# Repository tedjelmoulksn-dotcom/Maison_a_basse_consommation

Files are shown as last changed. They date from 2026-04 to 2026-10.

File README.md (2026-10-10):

# Embedded Energy-Efficient House

An Arduino-based house demonstrator integrating temperature measurement, thermal actuation and motorized mechanisms. The project connects embedded control software with an energy-efficiency study and a physical model.

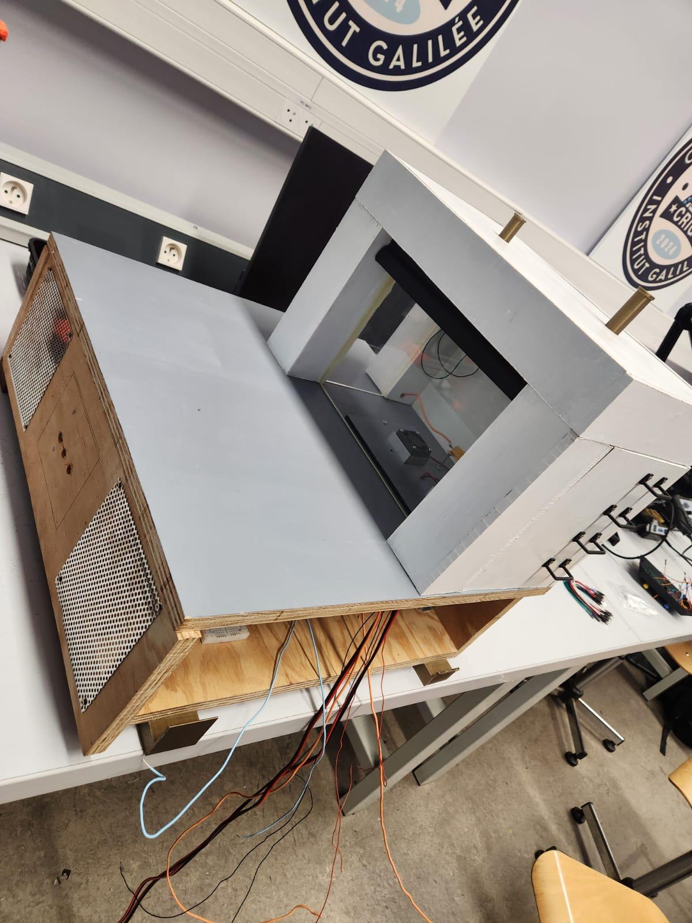
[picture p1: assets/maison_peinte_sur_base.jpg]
Maison a basse consommation project overview


*Assembled house model with its integrated control hardware.*

## Embedded architecture

The firmware reads a **TCN75A temperature sensor over I²C** and presents information on a **20 × 4 I²C LCD**. Buttons select operating modes. GPIO and PWM outputs drive heating, a Peltier element, ventilation and a simulated sun source; a stepper motor and servo control the mechanical demonstration.

| Interface | Implementation |
| --- | --- |
| Temperature acquisition | TCN75A at address `0x48`, local C++ driver |
| Display | LCD at address `0x27` |
| User input | Buttons with internal pull-ups |
| Actuation | Heater, Peltier, fan, light, stepper and servo |
| Diagnostics | Serial output at 9600 baud |

## Repository guide

- [arduino](arduino/): application sketch, sensor driver and shutter support.
- [cad](cad/): mechanical design files.
- [documentation](documentation/): report and poster.
- [assets](assets/): prototype photographs.
- [tests](tests/): host-side checks and Arduino stubs.

## Getting started

Open the sketch in Arduino IDE and install its LCD, stepper and servo dependencies. Confirm the pin assignments in the sketch against the wiring before uploading.

The supplied software includes demonstration modes and component-level tests. Full thermal regulation and assembled-system behaviour require validation on the physical prototype.

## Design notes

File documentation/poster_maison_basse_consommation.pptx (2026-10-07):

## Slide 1

Maquette d’une maison énergétique intelligente : régulation thermique autonome

Greg ALBERTS, Sarah DAHMOUN, Hugo LEBAUD, Tedj El Moulk SINACER
Encadrant : Gabriel DUTIER, LPL, gabriel.dutier@univ-paris13.fr

Cycle ingénieur 2ème année – Instrumentation et Systèmes Embarqués – Sup Galilée – USPN

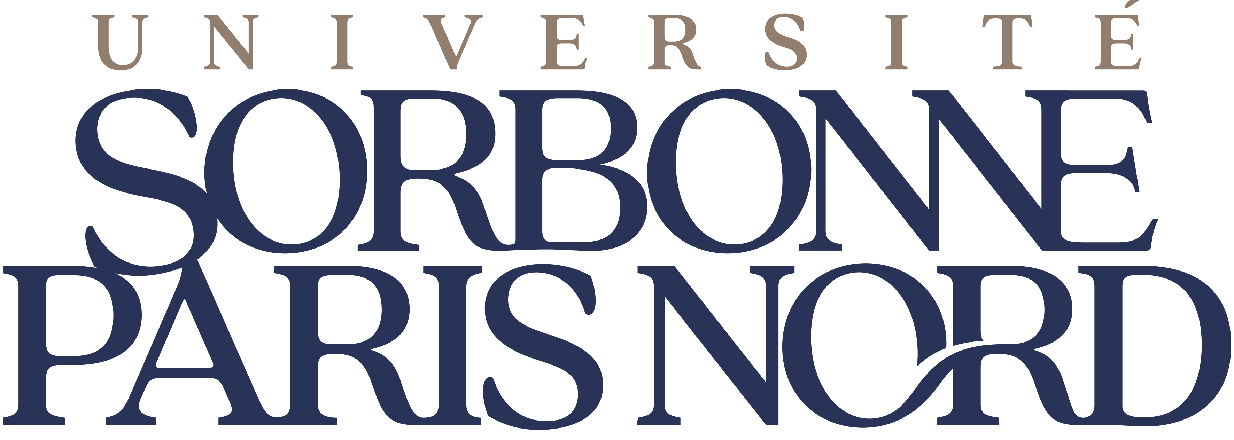
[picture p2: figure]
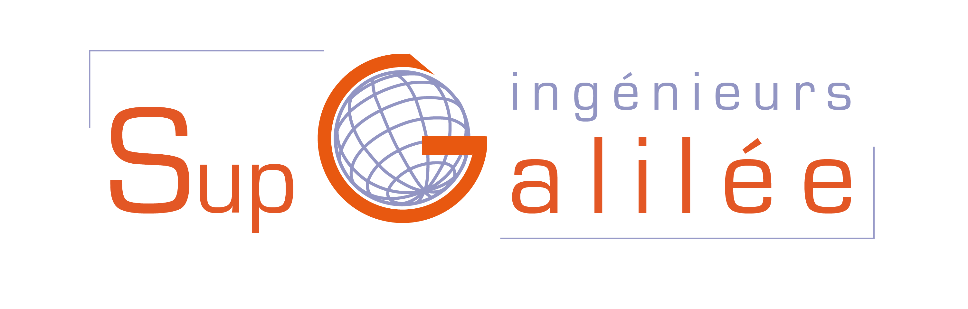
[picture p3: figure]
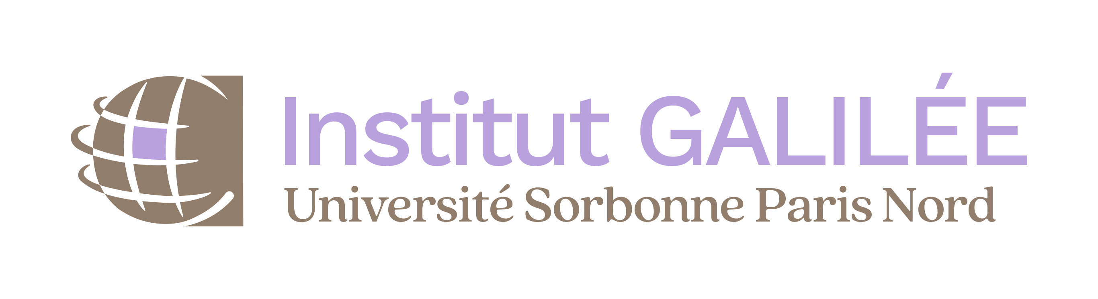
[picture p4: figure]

1- Contexte et objectif
Contexte :
- En France et en Europe le secteur du bâtiment représente
environ 40% de la consommation énergétique totale.
- L’optimisation des systèmes de régulation thermique est
un levier concret d’action
Pourquoi une maquette ?
- Permet de tester des solutions en conditions simulées
- Reproduire le comportement thermique d’une maison
à petite échelle

Objectif :
Créer une maison miniature capable de réguler sa température selon la saison et en autonomie.

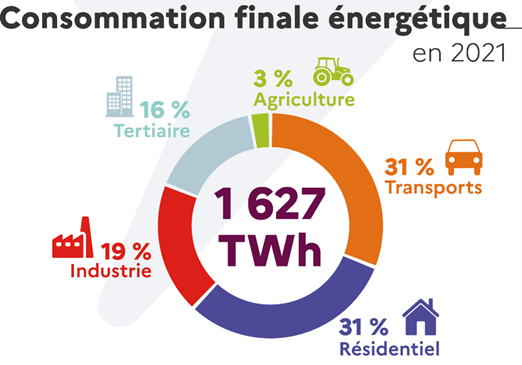
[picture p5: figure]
Point sur la situation énergétique en Europe

2- Stratégie
Liste du matériel :
- Contrôle de la température intérieure :
- Résistance
- Ventilateur
- Contrôle de la température extérieure:
- Soleil
- Peltier
- Actionneur :
- Volet motorisé par un moteur pas-à-pas
- Carte Arduino méga

Réalité | Maquette
Température extérieure dépend de la météo | Température extérieure simulée et contrôlée
Taille: dissipation thermique lente | Taille: dissipation thermique rapide
Isolation : matériaux adaptés (ex: l'air) | Isolation : mur de la maison en bois

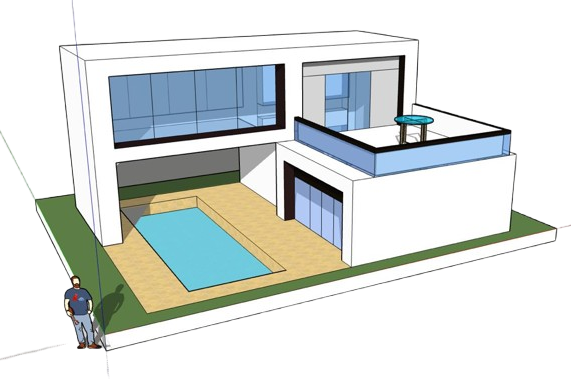
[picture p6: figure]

3- Architecture du système
A- Montage électrique

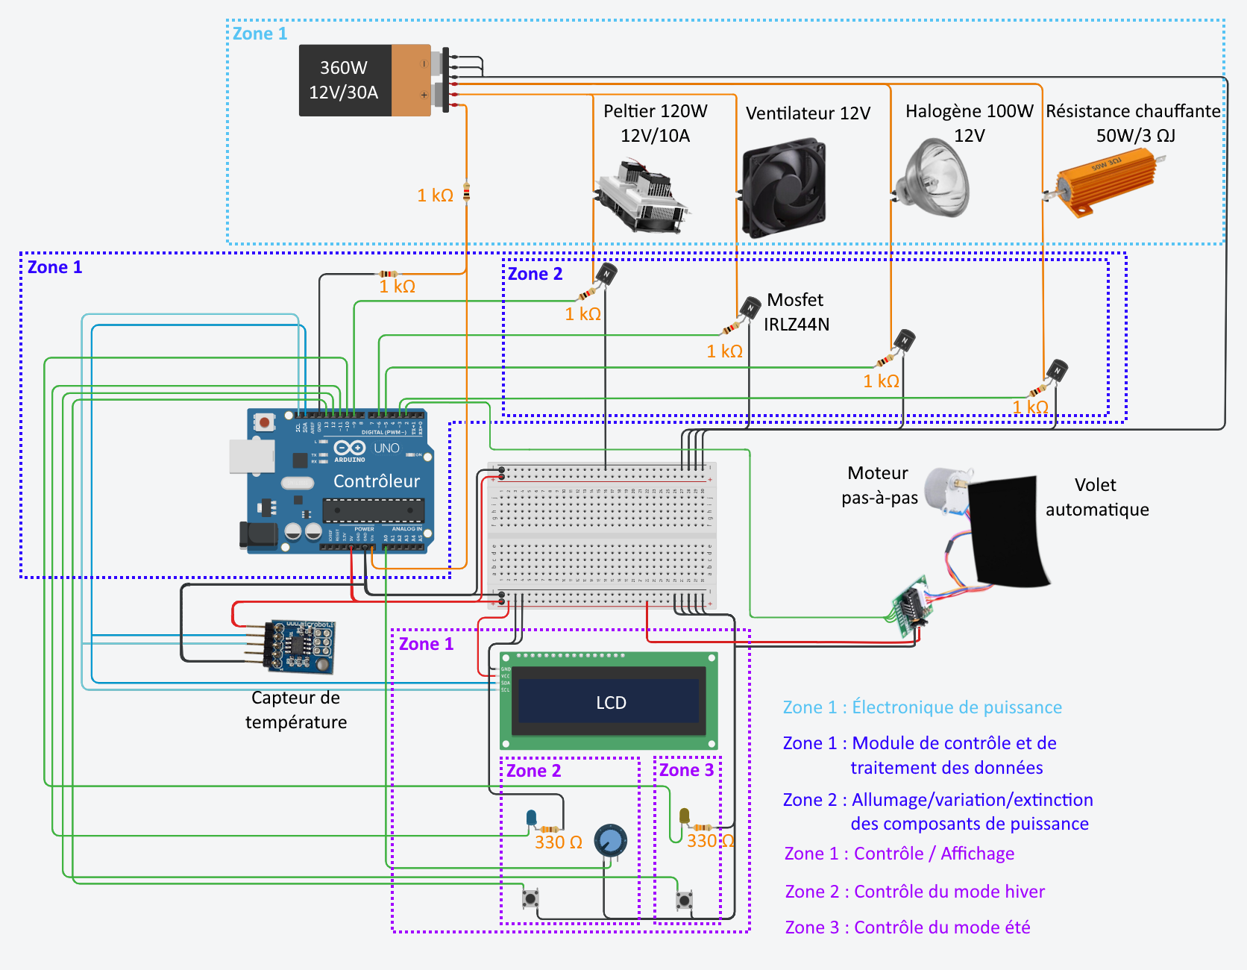
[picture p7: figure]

B- Schéma bloc

Été

Mode été ou hiver ?

Hiver

PWM ampoule halogène à intensité élevée

Lire température intérieure T

PWM Peltier pour refroidir la maison

Lire température intérieure T

T < 21°C

Ouvrir le volet

T > 21°C

Fermer le volet

Ouvrir le volet
Activer résistance

Lancer PID pour
Chauffer jusqu’à 21-23°C

T < 21°C

T > 23°C

Fermer le volet
PID => T consigne

Couper résistance si T>23°C

Revenir à la lecture de température
(boucle)

4- Conclusion
A- Difficultés rencontrés
- L’isolation
- Complexité de la gestion du flux d’air
- Simuler la température d'un environnement extérieur
- Construire une maison qui puisse contenir tous les éléments de domotique à cette échelle

B- Améliorations
- Ajout de panneau solaire
- Mesure de la luminosité/Humidité
- Contrôle via une application

Références :
https://www.intercommunalites.fr/actualite/point-sur-la-situation-energetique-en-europe/

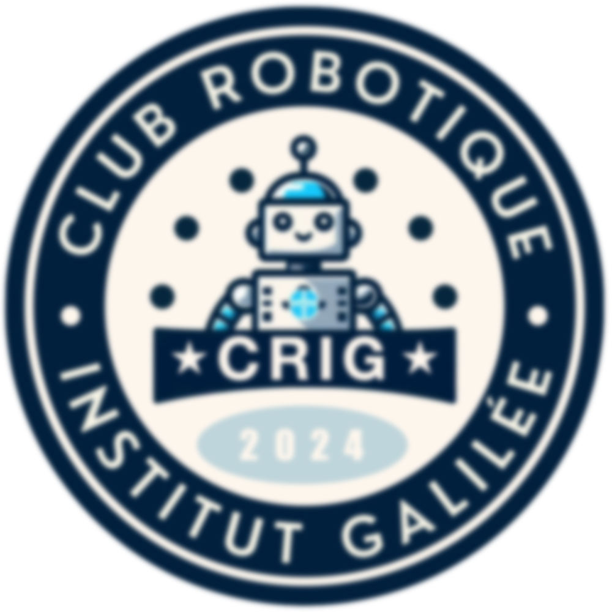
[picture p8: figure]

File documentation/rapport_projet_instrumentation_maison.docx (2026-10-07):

# Onglet 1

Greg ALBERTS 31/05/2025

Sarah DAHMOUN

Hugo LEBAUD

Tedj el moulk SINACER

Projet Instrumentation (PROJET N°6) :

Maquette de démonstration d’une habitation modèle de sobriété énergétique

Tuteur : M. DUTIER Année Scolaire : 2025-2026

Sommaire

I. Définition du projet……………………………………………………………………………
  A. Contexte………………………………………………………………………………
  B. Stratégie………………………………………………………………………………
  C. Hypothèses…………………………………………………………………………..
  D. Cahier des charges………………………………………………………………….
  E. Fonctionnement de la maquette…………………………………………………...
II. Présentation du travail……………………………………………………………………….
  A. Répartition des tâches………………………………………………………………
  B. Organisation de l’équipe…………………………………………………………….
  C. Méthodologie de travail……………………………………………………………..
III. Présentation détaillée des résultats obtenus………………………………………………
IV. Analyse et discussion rigoureuse des résultats obtenus et de leurs limites……………
V. Conclusion……………………………………………………………………………………..
  A. Apport de ce projet.…………………………………………………………………..
  B. Erreurs commises……………………………………………………………………
  C. Difficultés rencontrées……………………………………………………………….
  D. Perspectives d’amélioration...……………………………………………………….
VI. Annexes…………….………………………………………………………………………….

# I. Définition du projet

# A. Contexte

Dans le cadre de ce projet, nous avons mêlé plusieurs domaines de l'ingénierie. Notamment, l'instrumentation et les systèmes embarqués qui font partie de notre spécialité ainsi que la partie énergétique qui est de plus en plus discutée et mise au cœur de notre société.

Pour ce faire, nous avons décidé de réaliser une maquette d’une maison énergétique afin de pouvoir nous rendre compte de l’impact des changements (température, éclairage, etc…) faits en temps réel. Cela nous permettra donc de pouvoir mieux appréhender et répondre aux questions/défis portant sur la sobriété énergétique dans nos futurs métiers d'ingénieurs.

  B. Stratégie

Pour la réalisation de cette maquette de démonstration nous devions faire un choix sur le type de grandeurs à mesurer ainsi que celles qui nous permettraient de répondre aux questions relevant de la sobriété énergétique. Autrement dit, à l’échelle de notre maquette qui est un exemple de maison énergétique autonome, nous ne pouvions pas agir sur tous les paramètres auxquels une maison réelle pourrait faire face avec nos moyens.

Pour cela, nous avons tenté de reproduire un type d’habitation déjà existant en nous basant sur des immeubles autonomes dans la périphérie de Lyon. En effet, cela nous permettait à la fois d’implémenter des systèmes autonomes et régulés (ex : volets automatiques en fonction de la température intérieure et extérieure) ainsi que de pouvoir discuter des défis énergétiques.

À cet effet, nous avons décidé de nous concentrer sur la grandeur suivante : la température (que nous détaillerons dans la suite de ce rapport).

  C. Hypothèses

Comme dit précédemment, le fait d’avoir une taille drastiquement plus faible que celle d’origine entraîne des impacts différents des paramètres qui agissent sur la maquette (sur la maison). Notamment la constante de temps pour laquelle il faudra attendre pour atteindre une température de consigne à l’intérieur de la maison sera différente de la réalité.

De plus, l’isolation de notre maquette de démonstration sera très différente des matériaux présents normalement par manque à la fois de matériaux, de place et de pertinence. Donc il y a nécessairement des choix à faire concernant l’isolation de la maison qui, ici, sera difficile à rapprocher de la réalité à cause de ces soucis.

En outre, pour obtenir une régulation de la température intérieure intéressante et optimisée, il nous faudra mettre un système de flux d’air ingénieux afin que le chauffage et le refroidissement de la pièce se fassent dans les meilleures conditions.

  D. Cahier des charges

Avec l’aide de notre tuteur, nous avons donc pu établir et mettre en place un cahier des charges en tenant compte de notre choix de stratégie ainsi que de nos hypothèses.

Tout d’abord, concernant la grandeur d’influence, nous avons choisi de réguler la température intérieure de la pièce à vivre tout en simulant la température extérieure selon des modes différents. Il y a les modes hiver et été, simulant l’environnement extérieur et permettant grâce à des leviers (volet automatique, chauffage intérieur) autonomes de compenser les fluctuations de températures et d’amener la maison à une certaine température de consigne.

De plus, concernant l’alimentation de notre système autonome, il nous a fallu utiliser une alimentation suffisamment importante nous permettant de supporter nos différents composants électroniques. En effet, le fait d’ajouter des composants simulant le chauffage et le refroidissement d’une pièce de cette envergure, nécessite une alimentation électrique assez puissante.

Pour ce qui est de la solution logicielle utilisée, il nous fallait une technologie répandue, facile d’accès et évolutive (afin que notre projet puisse être repris les années futures). Nous avons opté pour une carte Arduino (Langage : C++) et notamment le modèle Mega AVR qui est intéressant pour son grand nombre de ports de connexions (les cartes ESP32 sont également très répandues mais comportent souvent moins de ports).

Enfin, ce projet servira comme maquette de démonstration donc il faut qu’elle soit la plus attractive et compréhensible. À cette fin, nous ajouterons des détails de manière à ce qu’elle soit présentée sans difficulté. Notamment avec des objets créés en impression 3D (logiciel de modélisation : Fusion360) ou encore d’autres objets explicites.

  E. Fonctionnement de la maquette

Nous allons désormais expliquer son fonctionnement et cela à travers 2 modes simulant l’hiver et l’été, qui sont activables par l’appui sur leur bouton respectif (boutons placés sur la plaque de contrôle située à l’avant), bleu pour l’hiver (respectivement jaune pour l’été).

Tout d’abord, le mode hiver. Dans ce cas, nous avions besoin de simuler la température extérieure en hiver (relativement froide et donc difficile à atteindre si l’on attend pas le mois de décembre...) ainsi que le soleil (grâce à une ampoule halogène de 100W, qui sera moins puissante qu’en été grâce à la commande PWM et généralement plus bas qu’en été grâce au servomoteur avec un angle inclinant l’ampoule davantage vers le sol) tout en atteignant une certaine température de consigne à l’intérieure de la maison (entre 21°C et 23°C). Pour cela, avec le potentiomètre (sur la plaque de contrôle placée à l’avant), nous pouvons ajuster la température extérieure simulée par le peltier (plus ou moins froid en fonction de la température extérieure souhaitée). Les ventilateurs (à l’intérieur de la maison permettent une meilleure répartition de l’air chauffé par la résistance chauffante qui viendra compenser la fraîcheur apportée par le peltier. Pour ce qui est du ventilateur dans la base (en dessous de la maison) ainsi que les grilles, nous permettent une gestion du flux d’air chaud plus efficace et ainsi éviter une surchauffe des composants (dans la base). De plus, dans le cas où la température intérieure est inférieure à 21°C, le volet automatique sera ouvert (pour accélérer l’approche à la température de consigne) et au-dessus de 23°C, il sera fermé (afin de rester dans la plage de consigne voulue). À l'aide d’une régulation PID via le retour du capteur de température intérieure, nous pourrons ainsi atteindre et nous stabiliser à la température de consigne.

Puis, le mode été. Dans ce second cas, nous avions besoin de nouveau de simuler la température extérieure en été (relativement chaude) grâce au soleil (plus puissant et généralement plus haut qu’en hiver). Pour cela, nous avons mis une plaque noire interchangeable sur le mur du fond (afin de se rendre compte de l’impact d’un mur noir d’un mur blanc, qui pour ce dernier est très peu performant car il n’y aura pas d’effet de serre). En effet, la plaque de couleur noire permettra de créer un effet de serre car le noir absorbe le visible absorbe dans le visible en renvoyant dans l’infrarouge ce qui est très important lorsque l’on souhaite réchauffer la pièce. Cela est possible grâce au soleil (une ampoule halogène très puissante). Ainsi lorsque la température intérieure est supérieure à 21°C, nous fermons le volet automatique et nous l’ouvrons lorsque lorsqu’il fait moins de 21°C à l’intérieur de la maison de manière à atteindre la plage de température correcte (21°C < T < 23°C).

Enfin, sur la plaque de contrôle située à l’avant, nous avons le retour des différentes températures affichées sur le LCD ainsi qu’une led indiquant le mode activé afin de rendre la démonstration la plus intuitive possible.

# II. Présentation du travail

  A. Organisation de l’équipe

Le travail sur ce projet a été mené de manière collective et structurée, avec une répartition des tâches qui s’est faite naturellement, en fonction des compétences et des préférences de chacun. Tout au long du projet, les choix techniques ont été validés régulièrement avec notre tuteur, ce qui nous a permis d’avancer de manière cohérente et efficace.

Dès le lancement du projet, nous avons travaillé ensemble à la définition du cahier des charges, en échangeant régulièrement avec notre tuteur. Cette étape comprenait les grandes décisions techniques telles que la simulation des saisons, la régulation de la température, la gestion du flux d’air, l’alimentation électrique ou encore le choix de la carte électronique. Ces décisions ont toujours été prises de manière collective et validées progressivement, ce qui nous a permis de structurer le projet autour d’objectifs clairs.

Le travail s’est organisé de façon itérative : conception, tests et ajustements ont souvent été menés en parallèle, avec des échanges constants entre les membres de l’équipe. Chaque phase, de la modélisation 3D à l’assemblage de la maquette, en passant par les essais des composants et le développement logiciel, a mobilisé plusieurs personnes, ce qui a renforcé la dynamique collective. Cette collaboration étroite nous a permis d’être réactifs face aux imprévus et de progresser ensemble.

Enfin, la bonne répartition du temps de travail, l’entraide au sein du groupe et la volonté commune de livrer un projet à la fois fonctionnel, pédagogique et soigné ont été des éléments clés dans la réussite de ce travail. Ce mode de fonctionnement a non seulement permis d’atteindre nos objectifs, mais a aussi favorisé un véritable esprit d’équipe tout au long du projet.

  B. Répartition des tâches

Tâche | Sous-tâche | Personnes impliquées
Réflexion et conception du modèle du projet | CAO | Greg, Hugo
| Recherches sur le sujet | Hugo, Sarah
Réalisation de la base de la maquette | Découpe des grosses planches en bois | Labo de mécanique
| Assemblage des planches | Hugo, Greg
| Ajout grilles d’aération | Sarah
| Peinture | Hugo, Toudja
| Pose du peltier | Greg
| Raccordement de tous les branchements | Greg, Toudja, Hugo
| Façade de contrôle | Greg
| Lampe halogène “Soleil” | Greg
Réalisation de la maison | Découpe des planches en MDF | Labo de mécanique
| Découpe des vitres en acrylique | Ludomaker
| Découpe et pose du volet électrique | Toudja
| Peinture | Toudja, Hugo
| Assemblage de la maison | Toudja, Greg, Sarah, Hugo
| Étanchéitée de la maison | Hugo, Sarah
| Pose du capteur de température | Toudja, Sarah
| Pose de la résistance | Toudja, Greg
Programmation | Volet roulant | Toudja
| Peltier | Sarah
| Asservissement de la résistance | Hugo
| Lampe soleil | Greg
| Façade de contrôle avec écran LCD | Greg
| Programme général été/hiver pour le fonctionnement correct de la maquette | Greg, Toudja, Hugo, Sarah

  C. Méthodologie de travail

Notre méthode de travail était assez simple : travailler sur le projet régulièrement sur nos heures libres. Nous avons un groupe whatsapp afin de communiquer les avancements ou bien les questions que l’on se pose à propos du projet. Étant membres du CRIG, nous avions tout le loisir de travailler dans l’IGlab, ce qui était pratique.

Nous communiquions aussi régulièrement avec notre enseignant encadrant M.Dutier. Avec des échanges plus ou moins longs sur l’avancement de notre projet ou bien nos questions ou problèmes éventuels. En plus de cela, nous devions faire un rapport mensuel concernant notre avancement et les tâches futures à réaliser.

# III. Présentation détaillée des résultats obtenus

Note préalable : en raison de contraintes techniques et de temps, nous n’avons pas pu réaliser des essais complets et rigoureux en conditions expérimentales réelles. Des difficultés, qui seront détaillées dans une section dédiée du rapport, ont retardé le montage électrique final. La résolution des problèmes n’est intervenue que tardivement dans le calendrier du projet, cela ne nous a donc pas permis d’effectuer des tests.

Cependant, afin d’illustrer le fonctionnement prévu de notre maquette, nous avons produit des données simulées réalistes et représentatives du comportement du système en mode été et en mode hiver, et en particulier dans le cadre d’une comparaison entre une régulation avec PID et une régulation sans PID.

Mode Été : Augmentation thermique contrôlée (Lampe + volet)

Temps (min) | PWM Peltier (%) | PWM Lampe (%) | Température intérieure (°C) | Volet | Commentaire
0 | 0 | 80 | 20.0 | Ouvert | Départ, température ambiante
1 | 0 | 80 | 20.6 | Ouvert | Chauffe rapide par la lampe inclinée
2 | 0 | 80 | 21.3 | Fermé | Volet fermé dès que le seuil est atteint
3 | 0 | 80 | 22.1 | Fermé | Température continue d'augmenter
4 | 0 | 80 | 22.9 | Fermé | Surchauffe, car aucune régulation n’a réduit le flux
5 | 0 | 80 | 23.5 | Fermé | Dépassement de consigne, risque de surchauffe
6 | 0 | 80 | 24.0 | Fermé | Inconfort thermique potentiel

Mode Hiver : Régulation de température avec et sans régulation

Pour le fonctionnement de la résistance, nous avons prévu un fonctionnement type asservissement. Cela permet un chauffage rapide et optimisé. Le système va suivre la température de consigne, ici 23 degrés et faire en sorte de s’y maintenir. Faire ce genre de réglage par un être humain en modifiant constamment la puissance du chauffage est demandeur en temps et peu optimisé car l’on risque de trop chauffer et de devoir ouvrir les fenêtres pour refroidir, puis chauffer à nouveau et ainsi de suite. C’est pourquoi nous avons pensé au régulateur PID.

Nous prendrons comme approximation du système l’équation suivante :

- T(t) : température en degrés celsius
- P(t) : puissance injectée par la résistance (via PWM) en Watt
- K : gain thermique en °C/Watt
- τ : constante de temps thermique (dépend de la masse thermique, isolation, etc.)

Dans notre cas, un système seulement PI est recommandé. En effet, le proportionnel ajuste rapidement. Tandis que l’intégrale élimine l’erreur statique. Or, la dérivée anticipe les variations en observant la vitesse des changements et dans le cas d'une maison même petite le système est plutôt lent, et ceci n'apporte pas d'amélioration. Donc la dérivée est inutile ou contre-productive à cause du bruit (surtout avec des capteurs discrets). Elle risque plus de créer de l'instabilité dans le système et serait dure à régler.

Temps (min) | État résistance (sans PI) | Température sans PI (°C) | État résistance (avec PI) | Température avec PI (°C) | Écart à la consigne (sans PI) | Écart à la consigne (avec PI)
0 | ON | 15 | ON | 15 | -8 | -8
2 | ON | 17.5 | ON | 19 | -5.5 | -4
4 | ON | 19.5 | PWM ⇓ | 21.5 | -3.5 | -1.5
6 | OFF | 21.5 | PWM ⇅ | 22.8 | -1.5 | -0.2
8 | OFF | 24.2 | PWM stable (basse intensité) | 23 | +1.2 | 0
10 | ON | 22 | PWM stable (basse intensité) | 23 | -1 | 0

# IV. Analyse et discussion rigoureuse des résultats obtenus et de leurs limites

Les données simulées ci-dessus permettent d’illustrer plusieurs phénomènes caractéristiques du système, notamment l'impact de la régulation sur la stabilité thermique.

Mode été

Dans le cas du mode été, la température intérieure est influencée uniquement par la puissance fixe de la lampe halogène et la position du volet automatique, qui s’ouvre ou se ferme en fonction d’un simple seuil de température. Cette stratégie présente rapidement des limites importantes :

- Montée en température non maîtrisée : dès que la température atteint 21 °C, le volet se ferme. Toutefois, la lampe reste allumée à pleine puissance (PWM = 80 %) et continue à chauffer la pièce, ce qui entraîne une surchauffe progressive.
- Absence de modulation : le système ne réduit pas l’intensité du chauffage (lampe), ce qui engendre un dépassement de la consigne. Nous avons fixé une consigne pour le mode hiver et pas le mode été, mais nous avons quand même choisi de fermer le volet à 21°C en estimant que cette température est idéale à l’intérieur, sauf que la fermeture du volet n'est pas suffisante pour stopper la montée en température.

Finalement le dépassement de la température de 3 degrés celsius démontre la nécessité d’une régulation de l’intensité de la source de chaleur, ce qui pourrait être obtenu en ajoutant une modulation de puissance via PWM.

Mode hiver

Dans le mode hiver, deux scénarios sont simulés : l’un avec un chauffage constant (tout ou rien) et l’autre avec une régulation PI qui représente le mode de fonctionnement prévu pour la maison.

Sans régulation PI :

Dans ce cas, la résistance est simplement activée ou désactivée selon des seuils.

La température monte rapidement, dépasse la consigne de 23 °C sans stabilisation, avec une tendance à surchauffer puis à compenser brutalement en éteignant le chauffage.

Cette méthode est peu efficace car elle génère des fluctuations thermiques importantes, et n’est pas viable pour un système autonome visant à optimiser l’énergie.

Avec régulation PI :

- La montée en température est plus rapide au départ (effet du terme proportionnel) puis stabilisée progressivement à proximité de la consigne grâce au terme intégral qui corrige l’erreur résiduelle.
- La puissance injectée par la résistance est modulée progressivement (via PWM), ce qui évite la surchauffe.
- À un moment (10min dans cette simulation ) , le système atteint la consigne avec zéro erreur statique (écart = 0 °C).
- L’élimination du terme dérivé est quant à lui ici justifiée : il n’apporterait que du bruit et une instabilité potentielle, surtout avec un capteur discret

Finalement l’étude comparative des régulations met en évidence l'intérêt d’un asservissement PI pour assurer le confort thermique pour assurer la stabilité du système et un confort thermique. En été, l’absence de contrôle de la source de chaleur créé une dérive thermique.

# V. Conclusion

  A. Apport de ce projet
- Découverte de l’électronique de puissance, notamment à travers la conception et le dimensionnement d’un circuit capable d’alimenter plusieurs composants (résistances chauffantes, module peltier, ampoule halogène).
- Approfondissement des notions énergétiques, avec une meilleure compréhension de la régulation thermique dans une habitation, et des enjeux liés à la sobriété énergétique.
- Compétences pratiques en construction (architecture de base, peinture et travaux manuels).
- Gestion du projet, avec une planification des étapes, adaptations aux imprévus techniques et tenue de rapports mensuels.
- Travail en équipe.
- Sensibilisation aux contraintes techniques réelles, notamment en matière d’alimentation, d’isolation thermique, et de choix des matériaux .
  B. Erreurs commises
- Branchement, mise des câbles dans les colonnes et fixation des composants avant le test du montage fini.
- Manque de travail théorique c’est-à-dire calcul des puissances dissipées par les composants et les MOSFET.
- Manque de questionnement des personnes dans le domaine de l’électronique de puissance.
  C. Difficultés rencontrées
- Dimensionnement du circuit électrique (choix des composants et de leurs disposition en fonction des contraintes techniques et en particulier les exigences énergétiques telle que l’alimentation et la dissipation).
- Assurer l'isolation de la maison.
- Gestion des composants hautes puissance (manques d’information théoriques, datasheet peu détaillées).
  D. Perspectives d’amélioration
- Réalisation de calculs de puissances.
- Séparer la phase de test du montage final.
- Ajouter un capteur de température dans la base afin de réguler et améliorer le flux d’air empêchant les surchauffes des composants.
- Ajouter des panneaux solaires/récupérer l’énergie produite par la maison.
- Améliorer l’isolation de la maison.

# VI. Annexes

- Document de suivi du mois de janvier :

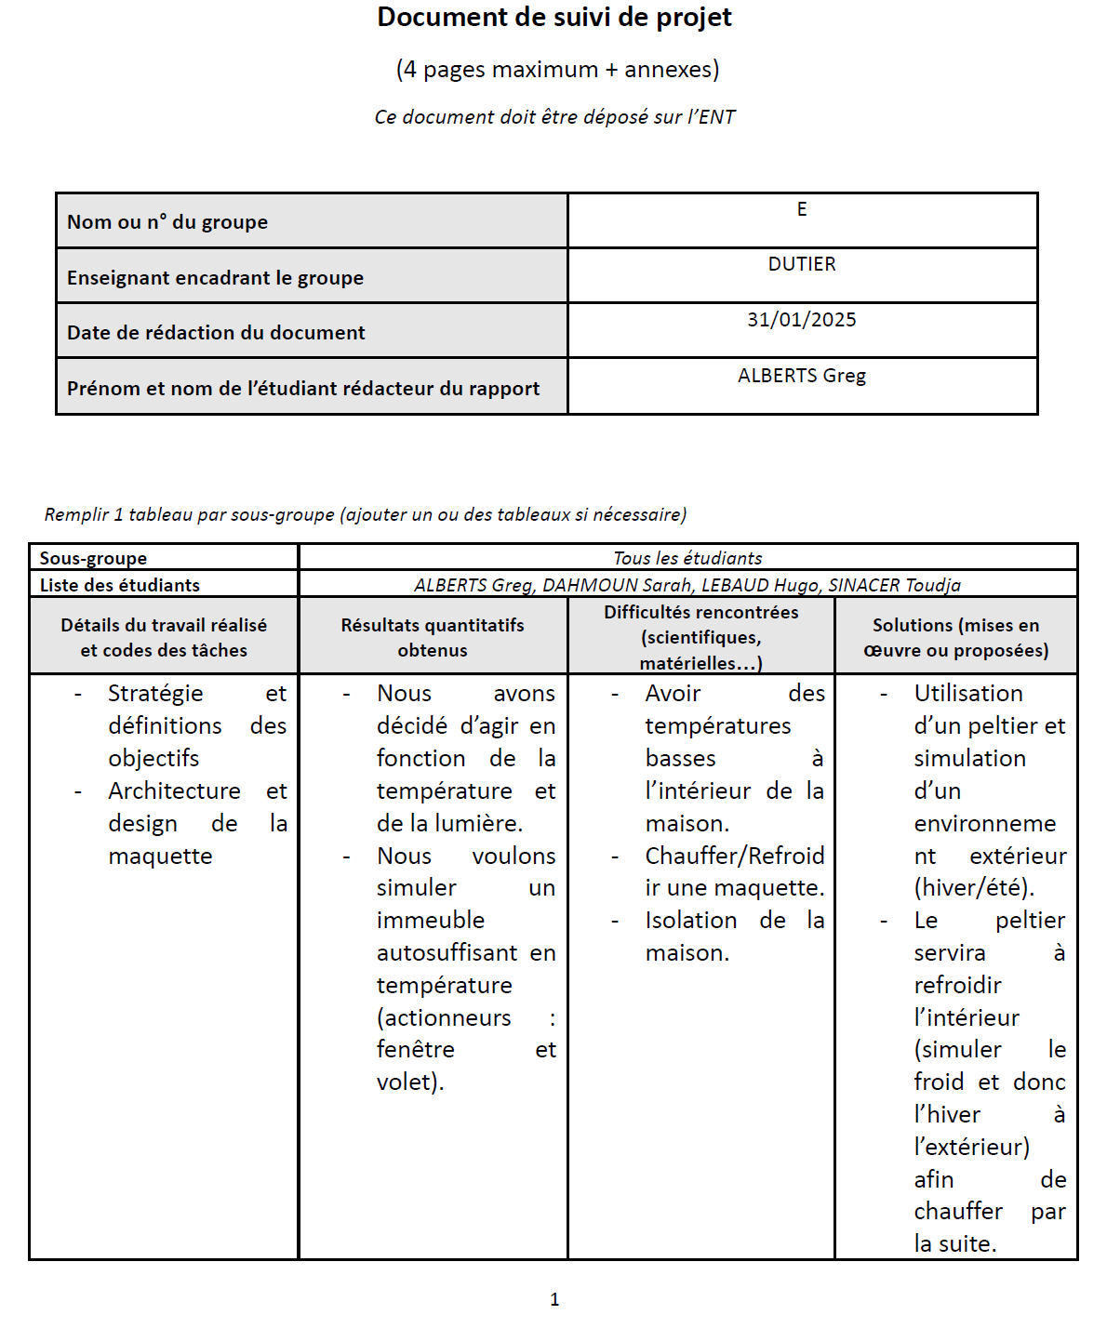
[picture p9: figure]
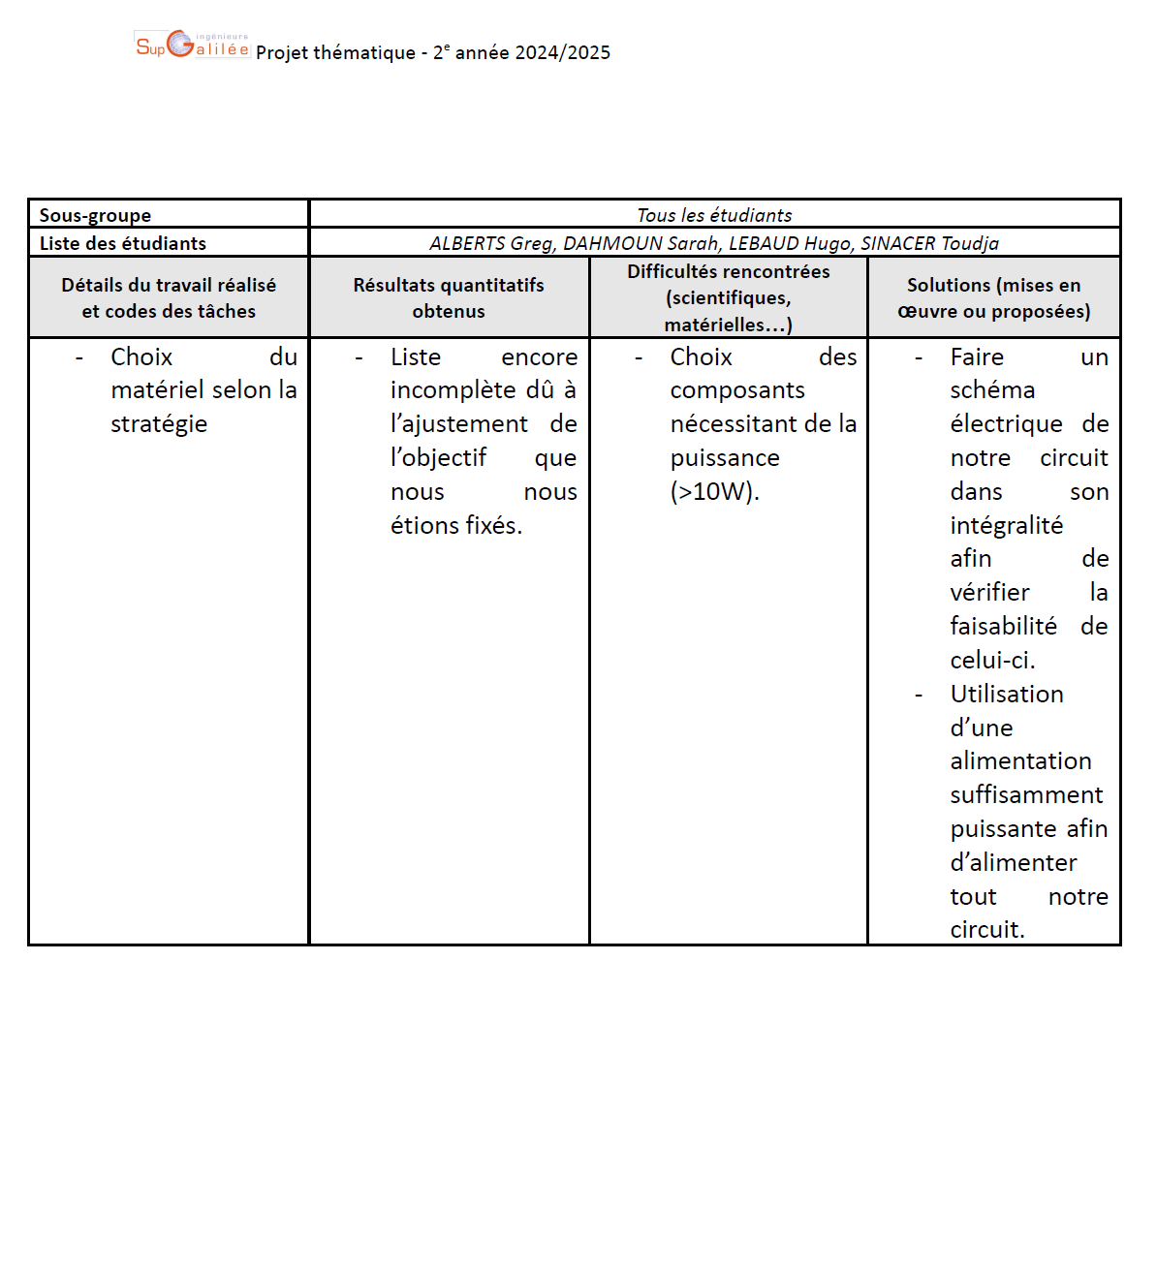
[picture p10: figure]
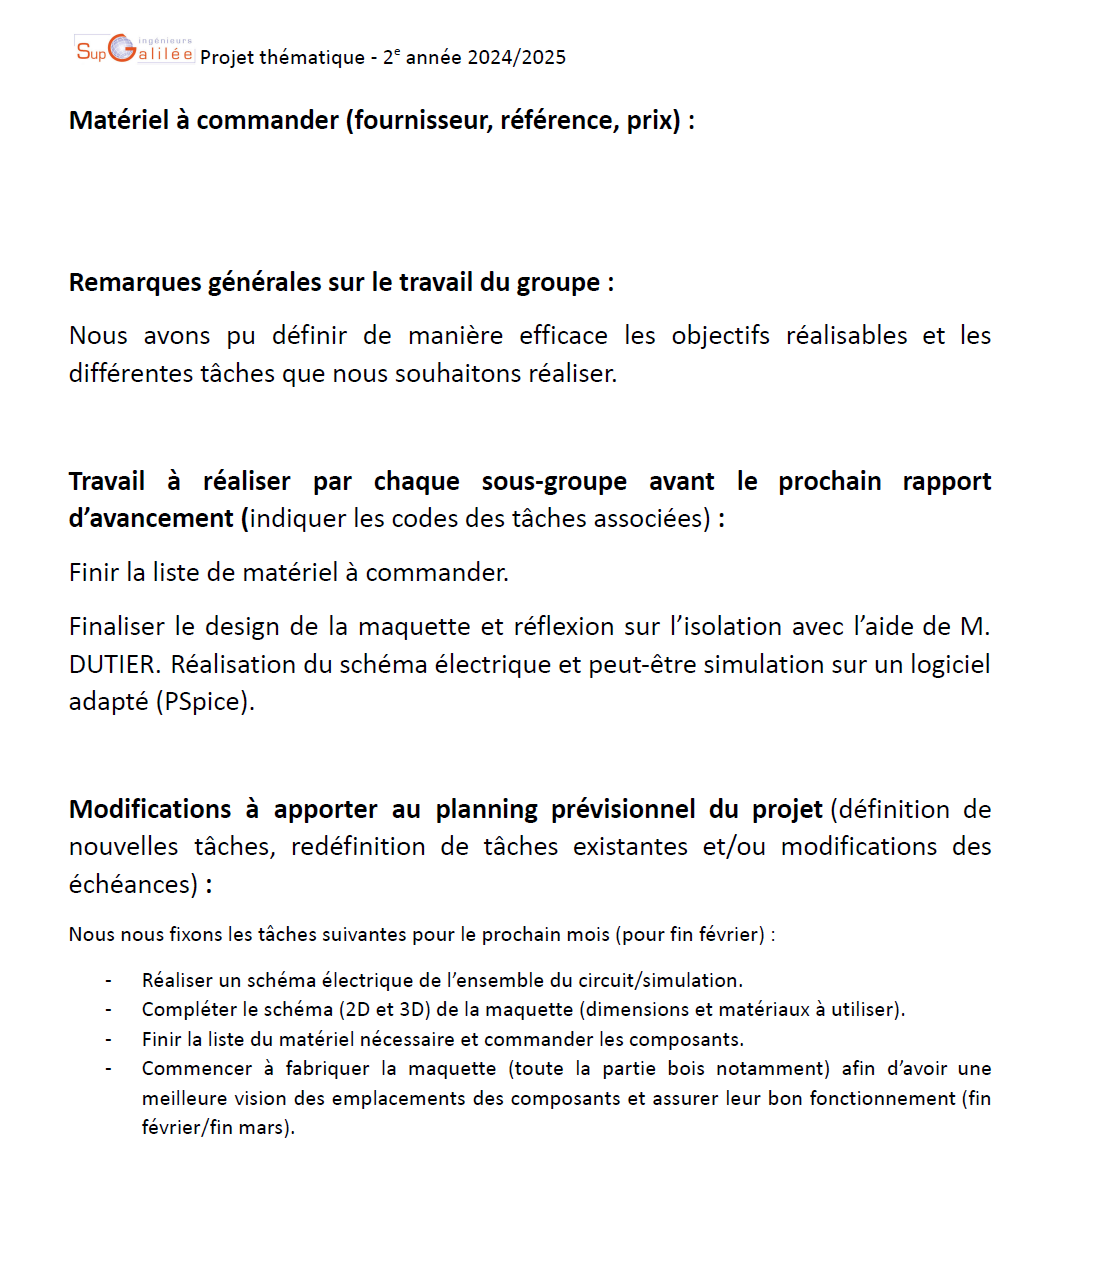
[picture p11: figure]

- Document de suivi du mois de février :

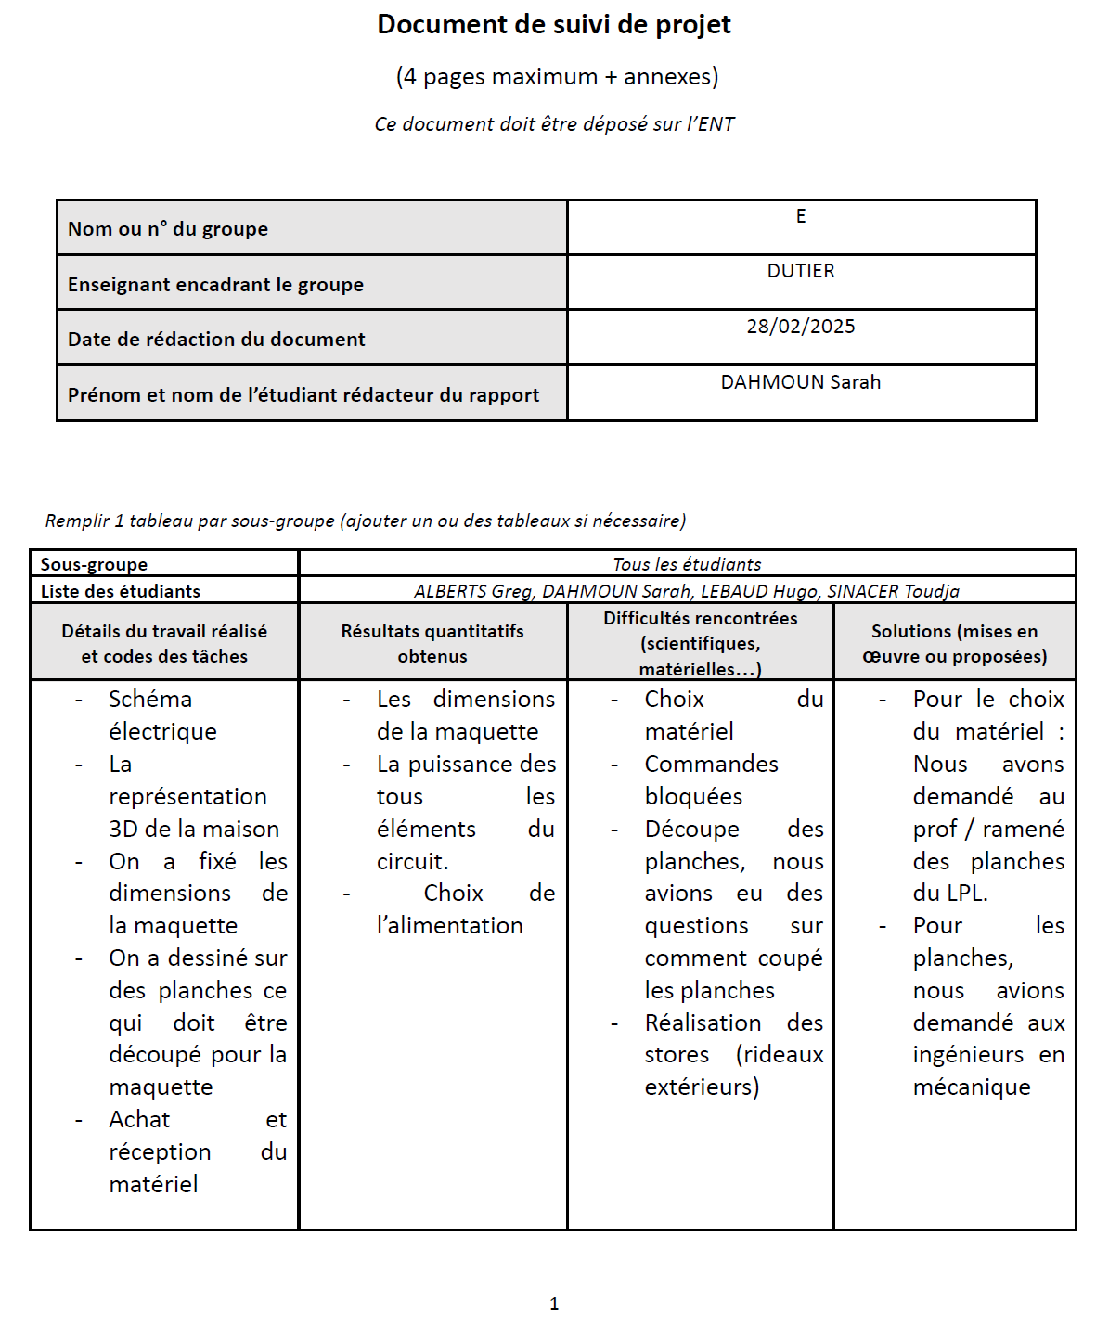
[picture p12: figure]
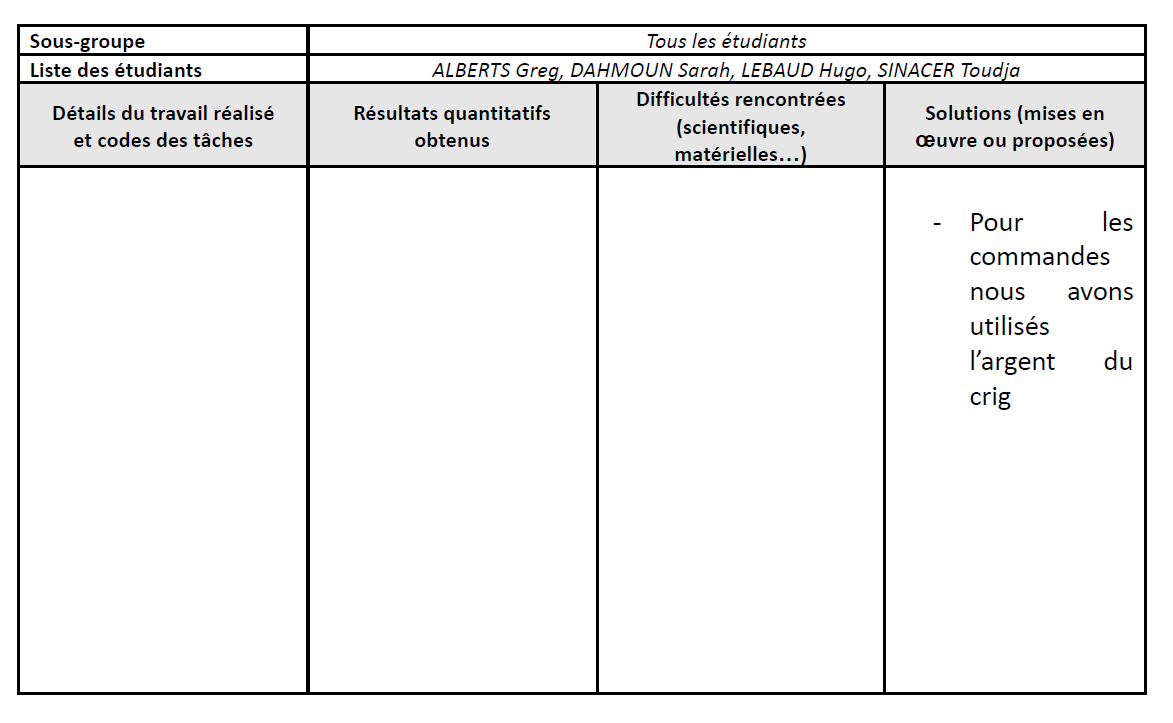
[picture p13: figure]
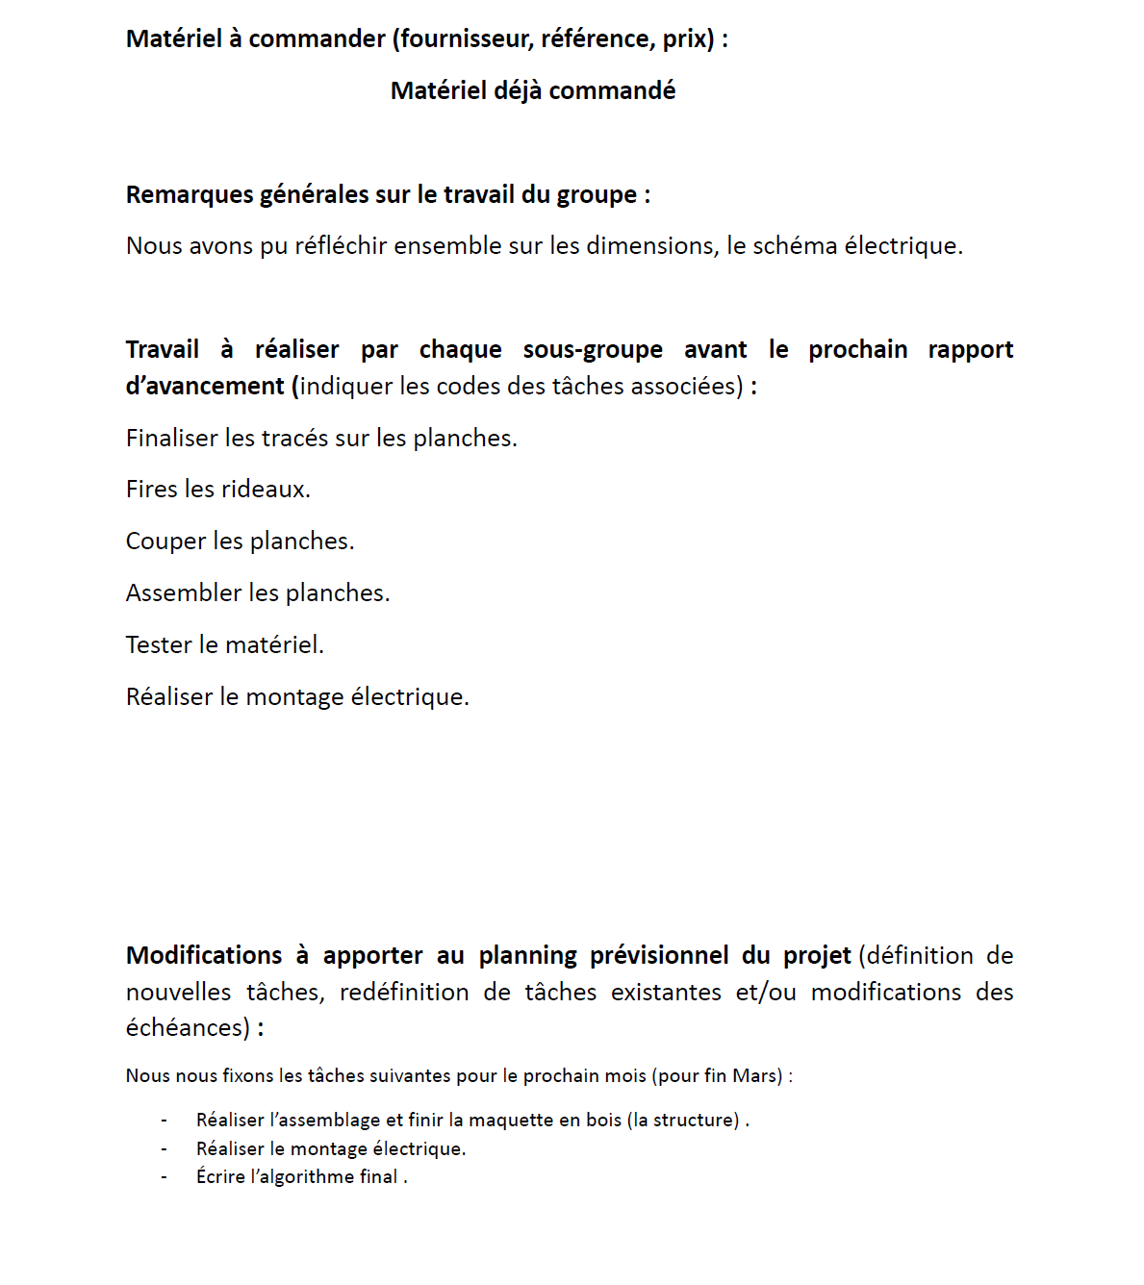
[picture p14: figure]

- Document de suivi du mois de mars :

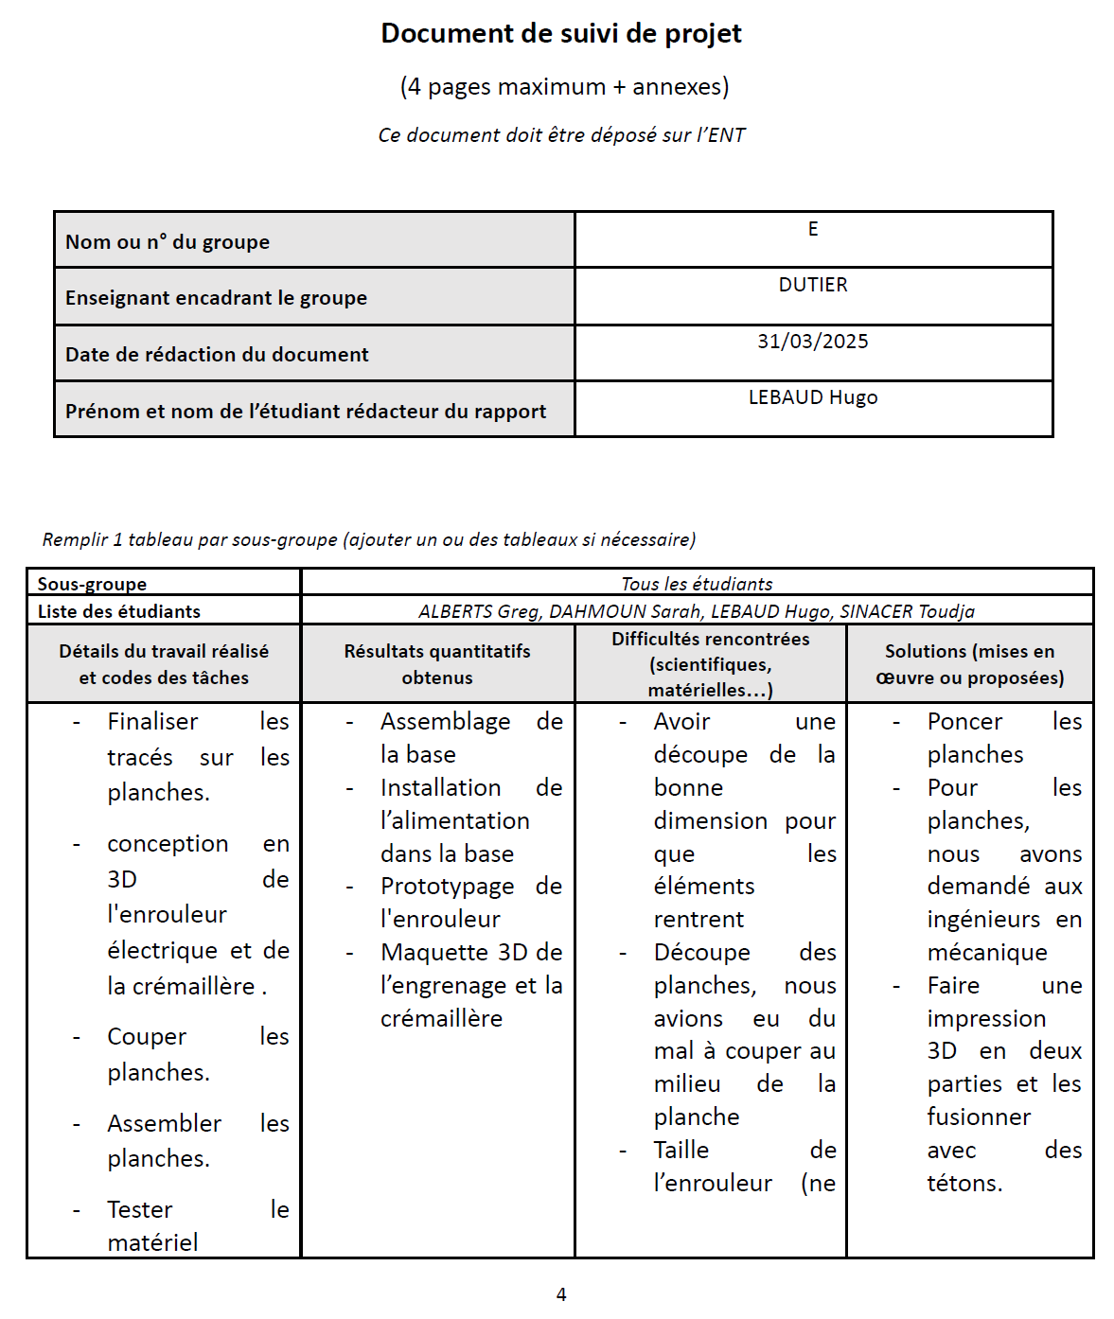
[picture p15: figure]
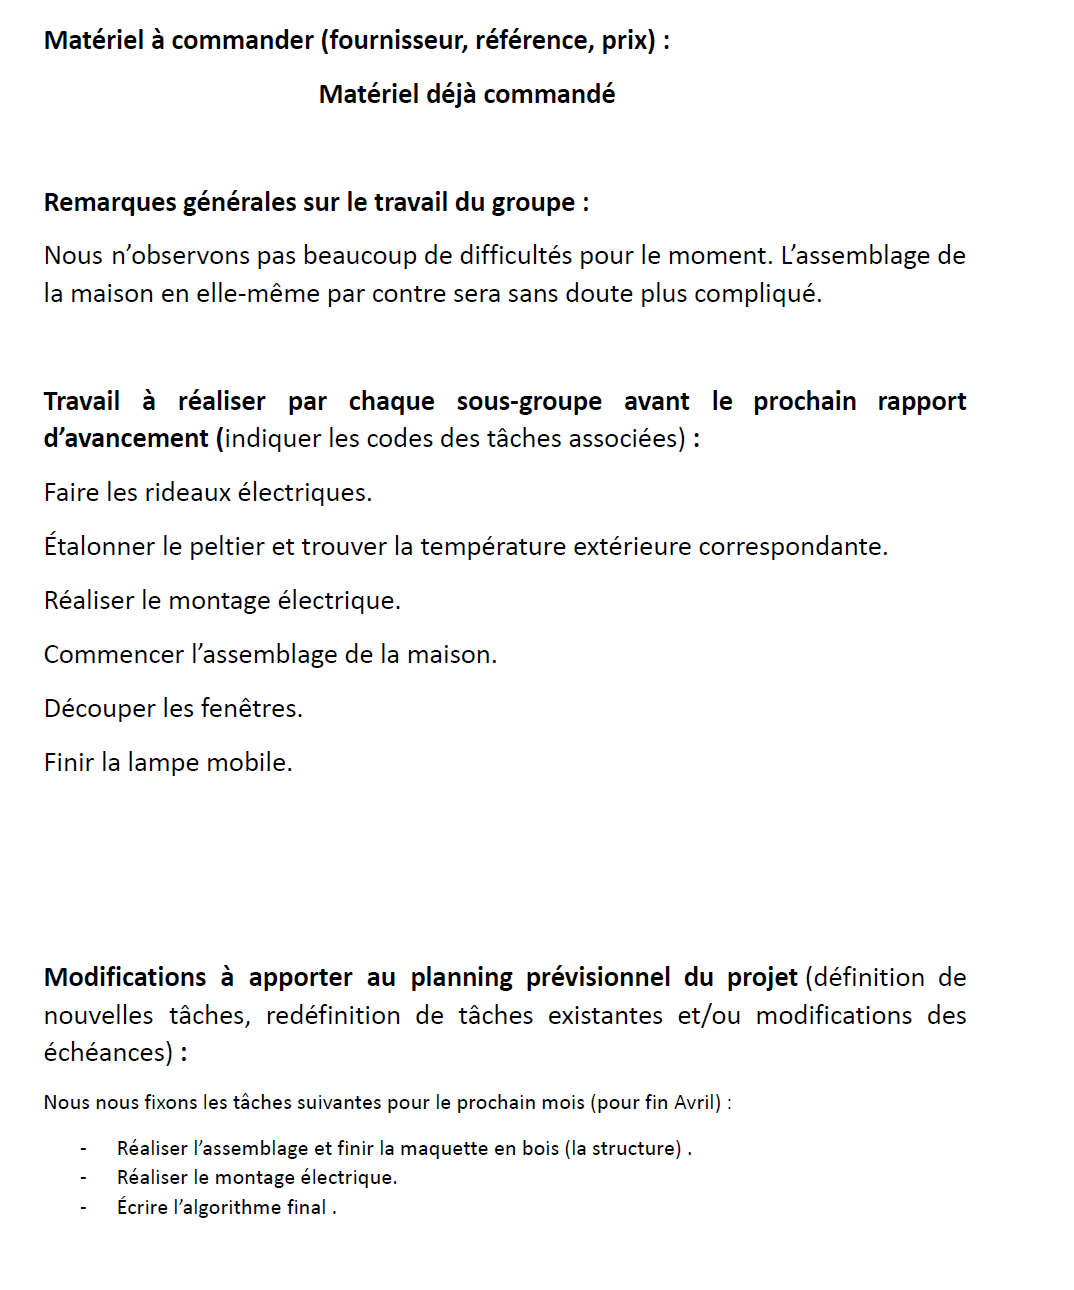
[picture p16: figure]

- Document de suivi du mois d’avril :

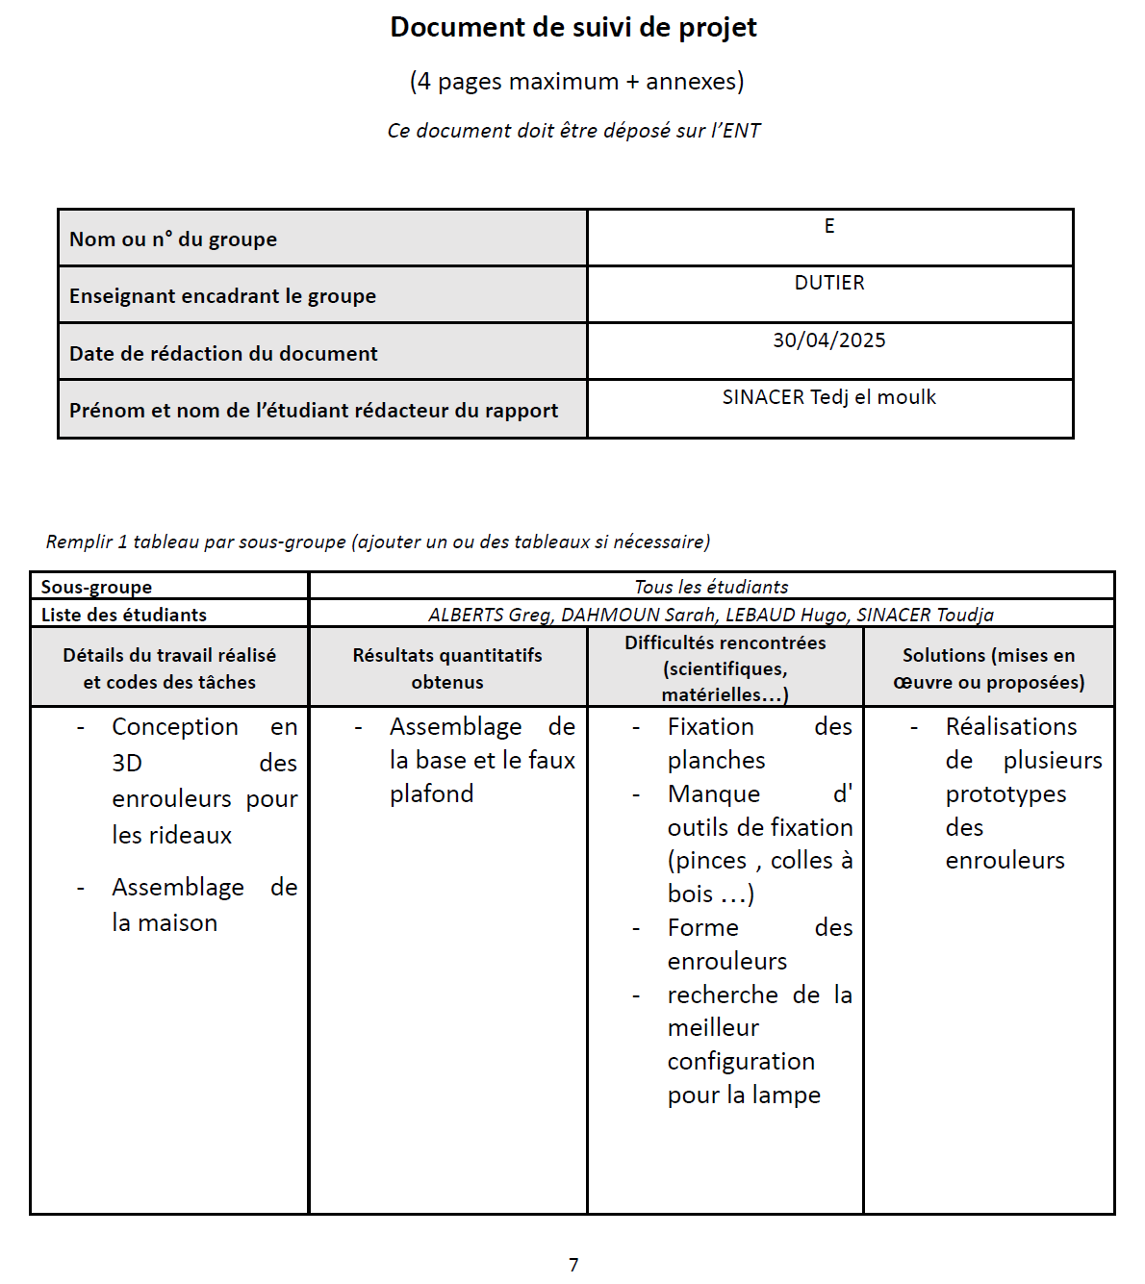
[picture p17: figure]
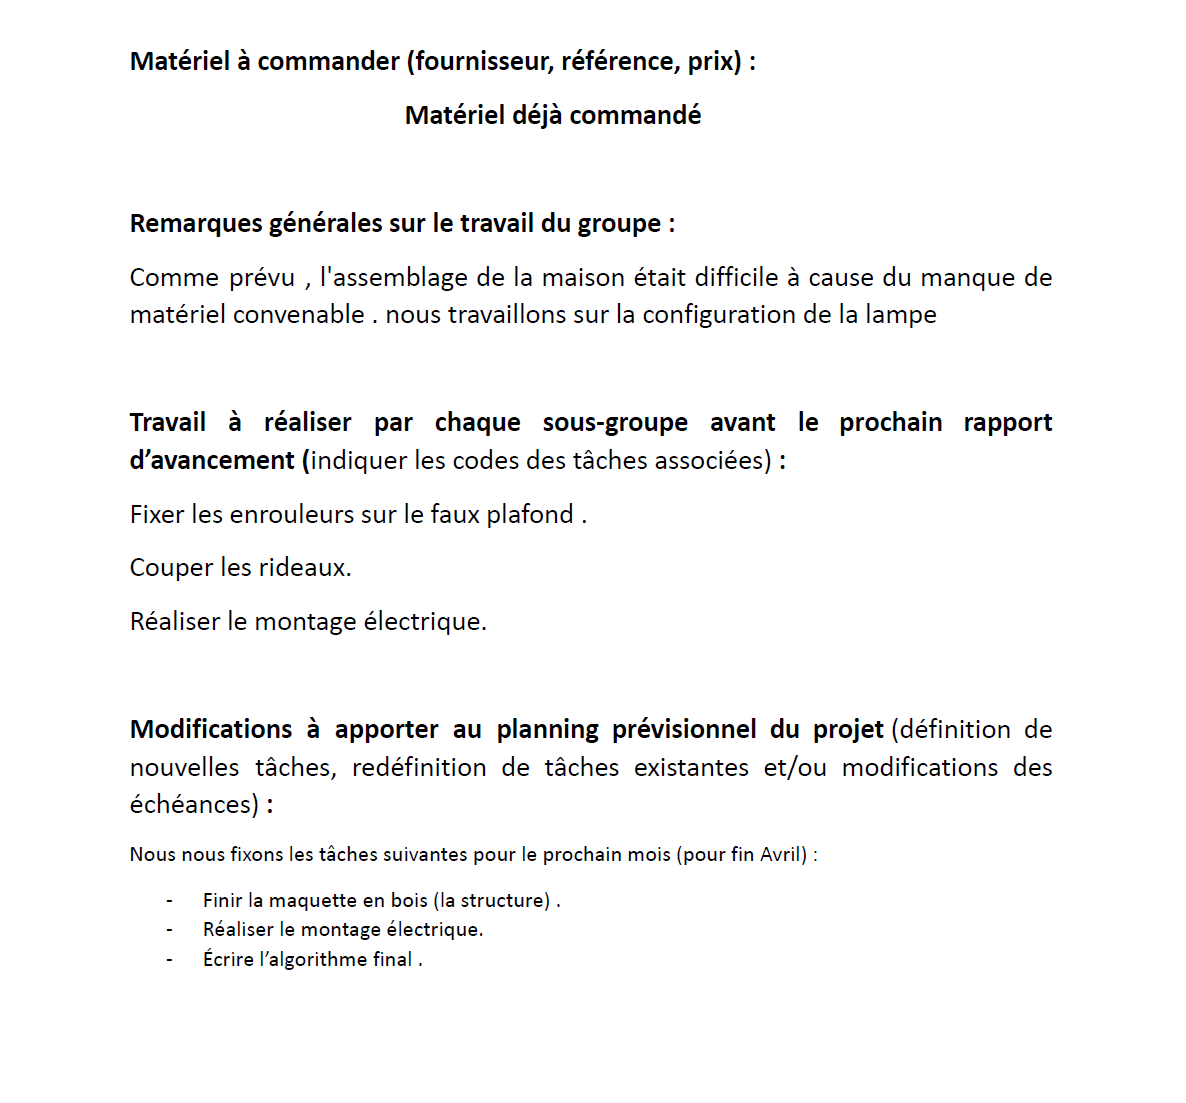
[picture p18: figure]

- Planification du projet de janvier à avril :

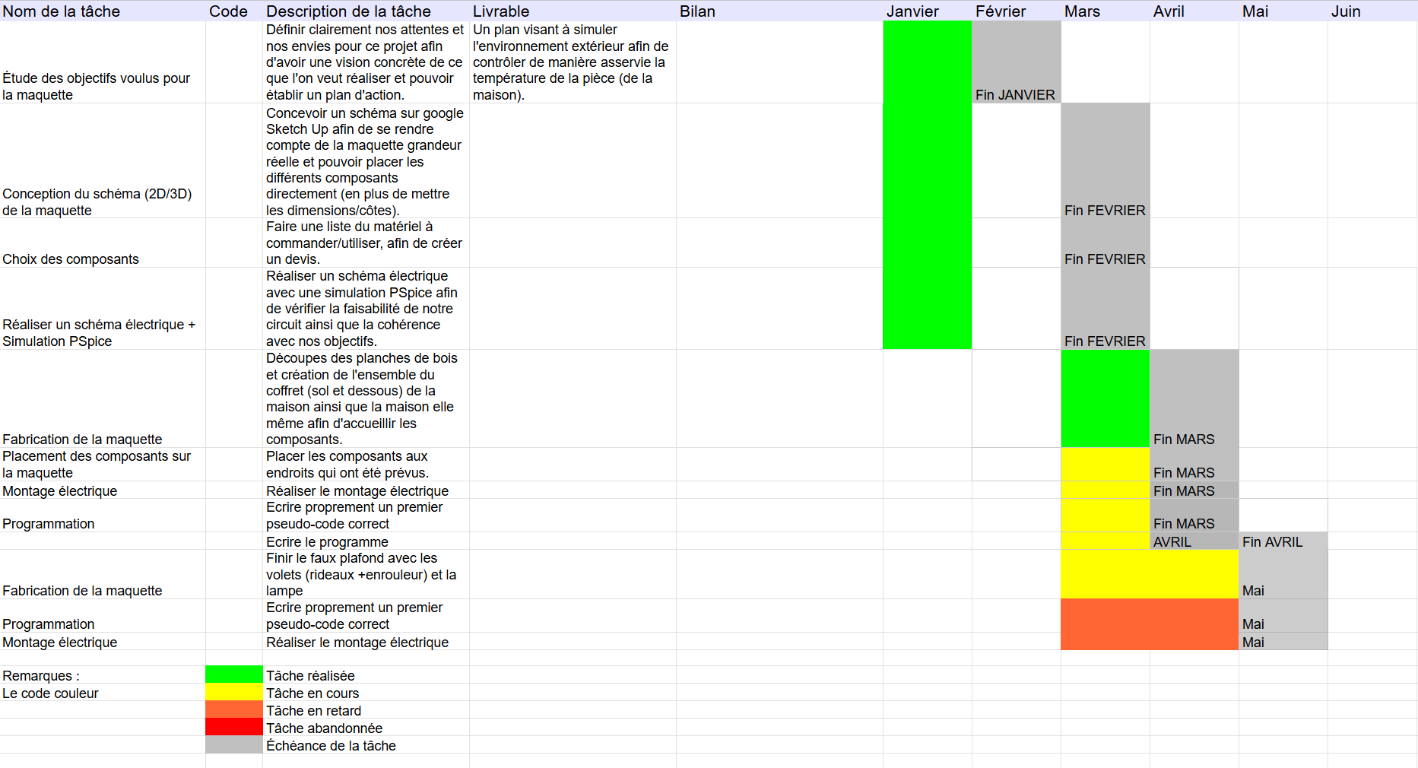
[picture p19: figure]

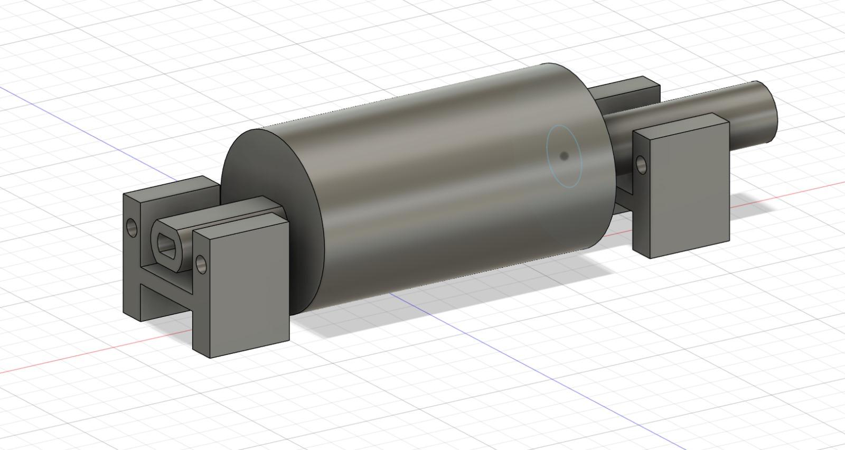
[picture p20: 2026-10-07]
assets/cao_enrouleur_volet.jpg

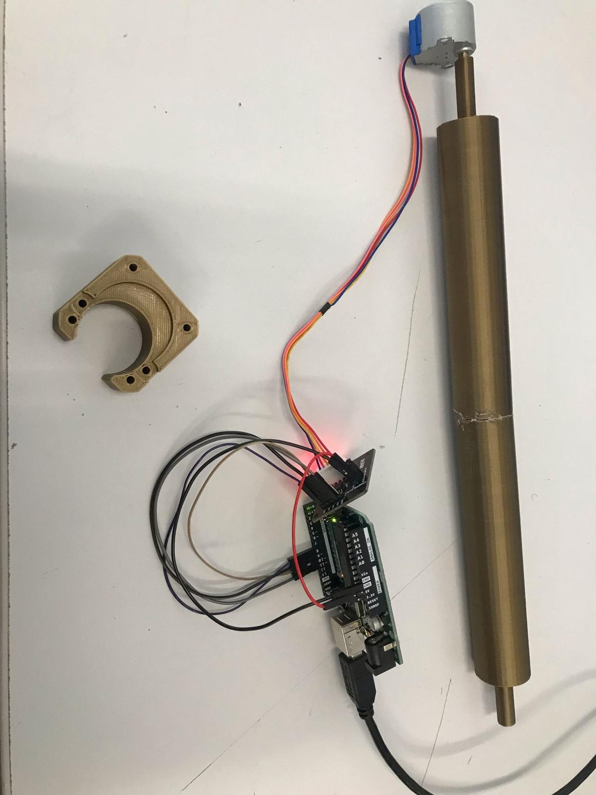
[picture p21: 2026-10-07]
assets/volet_enrouleur_moteur_pas_a_pas.jpg

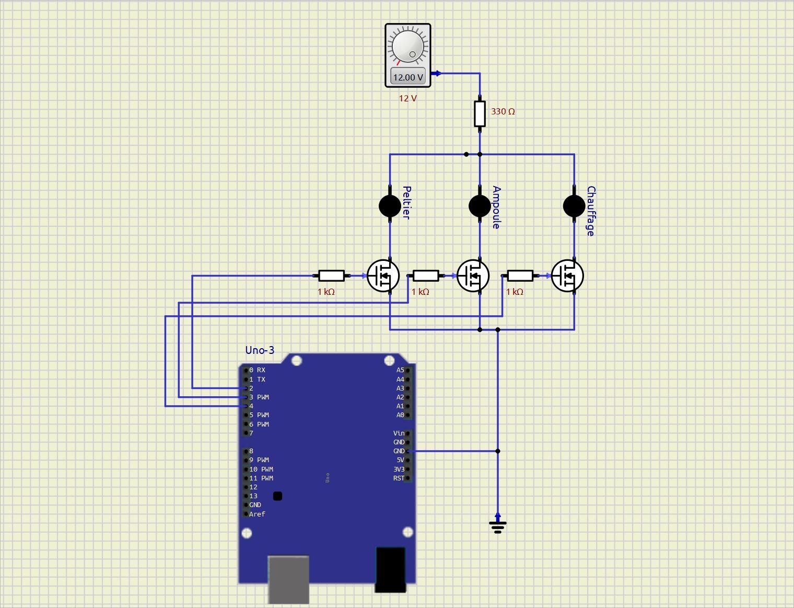
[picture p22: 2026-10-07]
assets/schema_commande_puissance_mosfet.jpg

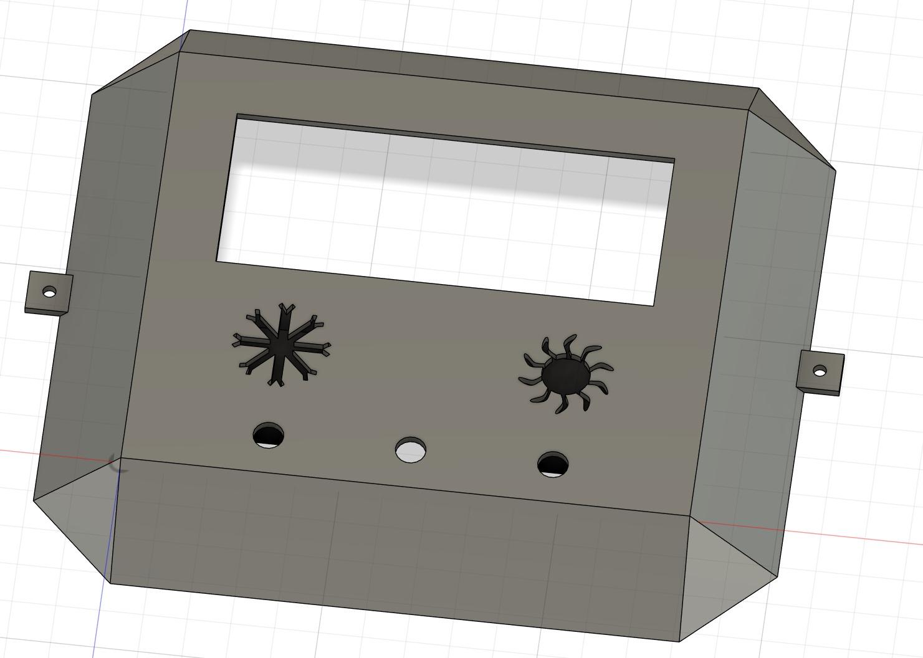
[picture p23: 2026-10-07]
assets/cao_facade_controle.jpg

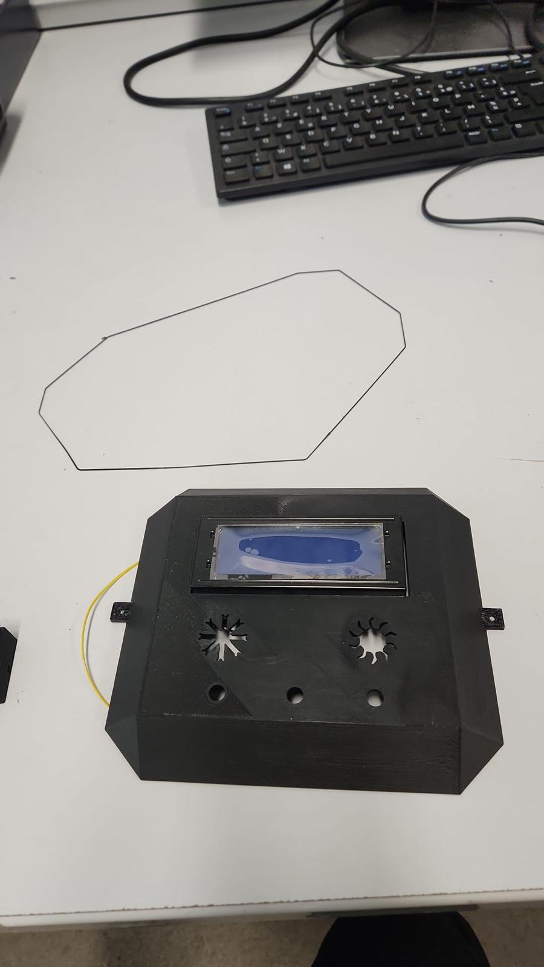
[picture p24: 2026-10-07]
assets/facade_controle_lcd.jpg

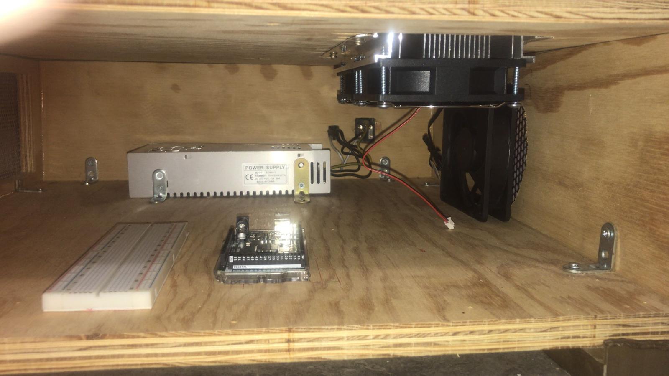
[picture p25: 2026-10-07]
assets/base_alimentation_ventilateur.jpg

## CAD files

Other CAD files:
cad/coffret_maison_energetique_v6.f3d
cad/enrouleur_volet_moteur_pas_a_pas_v2.f3d

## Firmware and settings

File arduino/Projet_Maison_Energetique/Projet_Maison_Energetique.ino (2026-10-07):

/* -------------------------------------------------------------------------------------------
| PROJET INSTRUMENTATION : Greg ALBERTS, Sarah DAHMOUN, Hugo LEBAUD, Tedj El Moulk SINACER   |
------------------------------------------------------------------------------------------- */

#include <Wire.h>   // library used with I2C protocol
#include "TCN75A.h"
#include <LiquidCrystal_I2C.h> // Nécessite l'installation de la bibliothèque LiquidCrystal_I2C 
#include <CheapStepper.h> //Librairie pour le module du moteur pas a pas 
                               //dans le gestionnaire de bibliothèque intégré à Arduino IDE

int nombre_de_pas = 4096*2;         // Nombre de pas pour un tour complet a tester surtout 
int position_defaut = 0;          // Position initiale

int pin_Peltier = 12; 
int pin_Resistance_Chauffante = 11;
int pin_Soleil = 10;
int pin_sig_ServoMoteurSoleil = 4;
int pin_Ventilateur = 13;
int pin_Bouton_Hiver = 2;
int pin_Bouton_Ete = 3;
int pin_Led_Hiver = 50;
int pin_Led_Ete = 37;
int pin_Potentiometre = 0;
CheapStepper stepper(32,28,30,22);// a choisir les pin convenable sinn c (8,9,10,11) par defaut;
TCN75A tcn(0x48);
LiquidCrystal_I2C lcd(0x27, 20, 4);
int compteur = 0;

void setup() {
  Serial.begin(9600);  // Initialise le port série
  Wire.begin();  // Initialise l'I2C avec les broches définies
  tcn.begin();  // Initialise le capteur
  lcd.init();// Initialise le LCD
  
  // Initialisation des pins
  pinMode(pin_Peltier, OUTPUT);
  pinMode(pin_Resistance_Chauffante, OUTPUT);
  pinMode(pin_Soleil, OUTPUT);
  pinMode(pin_Ventilateur, OUTPUT);
  pinMode(pin_Bouton_Hiver, INPUT_PULLUP);
  pinMode(pin_Bouton_Ete, INPUT_PULLUP);
  pinMode(pin_Led_Hiver, OUTPUT);
  pinMode(pin_Led_Ete, OUTPUT);

  // Enregistrer la position par défaut
  position_defaut = stepper.getStep();
  Serial.print("Position par défaut : ");
  Serial.println(position_defaut);
}

void loop() {  
  // Mode Ete
  if(digitalRead(pin_Bouton_Ete) == LOW)
  {
    // fonctionTest_TemperatureSensor();
    // fonctionTest_MoteurPasAPas();
    // fonctionTest_Peltier(100);
    fonctionTest_ResistanceChauffante(100);
    fonctionTest_Soleil(50);
    fonctionTest_Ventilateur(255);
    // fonctionTest_Lcd();
    // fonctionTest_Led();
    // fonctionTest_Bouton();
    // fonctionTest_Potentiometre();

    digitalWrite(pin_Led_Ete, HIGH);
    digitalWrite(pin_Led_Hiver, LOW);

    // fonctionTest_Lcd();
  }
  // Mode Hiver
  else if(digitalRead(pin_Bouton_Hiver) == LOW)
  {
    // fonctionTest_TemperatureSensor();
    // fonctionTest_MoteurPasAPas();
    // fonctionTest_Peltier(100);
    fonctionTest_ResistanceChauffante(0);
    fonctionTest_Soleil(0);
    fonctionTest_Ventilateur(255);
    // fonctionTest_Lcd();
    // fonctionTest_Led();
    // fonctionTest_Bouton();
    // fonctionTest_Potentiometre();

    digitalWrite(pin_Led_Hiver, HIGH);
    digitalWrite(pin_Led_Ete, LOW);

    // fonctionTest_Lcd();
  }

  fonctionProjet_TemperatureSensor();
}

/* ----- Début : FONCTIONS DU PROJET ----- */

// Fonction permettant selon le composant, de lui envoyer une commande PWM
void fonctionProjet_PWM(char* nom_composant, int valeur_PWM)
{
  if(nom_composant == "PELTIER")
  {
    analogWrite(pin_Peltier, valeur_PWM);
  }
  else if(nom_composant == "RESISTANCE")
  {
    analogWrite(pin_Resistance_Chauffante, valeur_PWM);
  }
  else if(nom_composant == "SOLEIL")
  {
    analogWrite(pin_Soleil, valeur_PWM);
  }
  else if(nom_composant == "VENTILATEUR")
  {
    analogWrite(pin_Ventilateur, valeur_PWM);
  }
}

// Fonction permettant de lire la température intérieure grâce au capteur
void fonctionProjet_TemperatureSensor()
{
  float t = tcn.readTemperature();
  
  if((compteur == 1) && (t > 32.0))
  {
    fonctionProjet_MoteurPasAPas();
    compteur = 2;
  }

  lcd.backlight();
  // Envoi du message sur le LCD : ----->>>> (colonne, ligne)
  lcd.setCursor(1,0);
  lcd.print("Temperature : ");
  lcd.setCursor(15, 0);
  lcd.print(t);
  lcd.setCursor(5, 1);
  lcd.print("compteur = ");
  lcd.setCursor(15, 1);
  lcd.print(compteur);
  delay(500);
  lcd.clear();

  Serial.println("Temperature : ");
  Serial.println(t);
  delay(500);
}

void fonctionProjet_MoteurPasAPas()
{
  // DESCENTE : faire 4096 pas dans une direction
  Serial.println("Descente...");
  for (int i = 0; i < nombre_de_pas; i++) {
    stepper.step(true);  // false = sens antihoraire
  }

  delay(2000); // Pause

  // REMONTER : refaire le même nombre de pas dans l'autre sens
  Serial.println("Remontée...");
  for (int i = 0; i < nombre_de_pas; i++) {
    stepper.step(false);  // true = sens horaire
  }

  delay(2000);

  Serial.print("Position finale (devrait être la même que la position de départ) : ");
  Serial.println(stepper.getStep());
}

/* ----- Fin : FONCTIONS DE TESTS DES COMPOSANTS ----- */

void fonctionTest_TemperatureSensor()
{
  float t = tcn.readTemperature();
  
  Serial.println("Temperature : ");
  Serial.println(t);
  delay(500);
}

void fonctionTest_MoteurPasAPas()
{
  // Placer le moteur à la position de départ (960)
  stepper.moveTo(true, position_defaut);
  Serial.print("Position initiale définie à : ");
  Serial.println(stepper.getStep());

  // Rotation de 180° (2048 pas) dans un sens (CW)
  Serial.println("Rotation de 180° dans le sens horaire (CW)...");
  for (int s = 0; s < 2048; s++) {
    stepper.step(true);  // Sens horaire
    if (stepper.getStep() % 64 == 0) {  // Affichage périodique
      Serial.print("Position actuelle : ");
      Serial.println(stepper.getStep());
    }
  }

  delay(1000);  // Pause

  // Retour à la position 960 en sens inverse 
  Serial.println("Retour à la position initiale ...");
  for (int s = 0; s < 2048; s++) {
    stepper.step(false);  // Sens antihoraire
    if (stepper.getStep() % 64 == 0) {
      Serial.print("Position actuelle : ");
      Serial.println(stepper.getStep());
    }
  }

  // Vérification de la position finale
  Serial.print("Position finale après retour : ");
  Serial.println(stepper.getStep());

  delay(1000);  // Pause avant de terminer
}

void fonctionTest_Peltier(int valeur_PWM)
{
  analogWrite(pin_Peltier, valeur_PWM);
}

void fonctionTest_ResistanceChauffante(int valeur_PWM)
{
  analogWrite(pin_Resistance_Chauffante, valeur_PWM);
}

void fonctionTest_Soleil(int valeur_PWM)
{
  analogWrite(pin_Soleil, valeur_PWM);
}

void fonctionTest_Ventilateur(int valeur_PWM)
{
  analogWrite(pin_Ventilateur, valeur_PWM);
}

void fonctionTest_Lcd()
{
  lcd.backlight();
  lcd.clear();
  // Envoi du message sur le LCD
  lcd.setCursor(0,0);
  lcd.print("Test");
  lcd.setCursor(1,5);
  lcd.print("du");
  lcd.setCursor(2,15);
  lcd.print("LCD");
  lcd.setCursor(3,0);
  lcd.print("Test I2C");
}

void fonctionTest_Led()
{
  digitalWrite(pin_Led_Hiver, HIGH);
  delay(200);
  digitalWrite(pin_Led_Hiver, LOW);
  delay(200);

  digitalWrite(pin_Led_Ete, HIGH);
  delay(200);
  digitalWrite(pin_Led_Ete, LOW);
  delay(200);
}

void fonctionTest_Bouton()
{
  if(digitalRead(pin_Bouton_Hiver) == LOW)
  {
    Serial.println("Bouton_Hiver : LOW");
  }
  if(digitalRead(pin_Bouton_Ete) == LOW)
  {
    Serial.println("Bouton_Ete : LOW");
  }
}

void fonctionTest_Potentiometre()
{
  int p = analogRead(pin_Potentiometre);
  int positon_Potentiometre = p/4;

  Serial.println("position_Potentiometre : ");
  Serial.println(positon_Potentiometre);
  delay(50);
}

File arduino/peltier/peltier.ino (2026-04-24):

// Broche de contrôle PWM du module Peltier
const int peltierPin = 5;  

void setup() {
  Serial.begin(9600);             // Initialisation la communication série
  pinMode(peltierPin, OUTPUT);    // Définition du pin comme sortie
  Serial.println("Envoie un chiffre de 1 à 5 pour régler la puissance du Peltier :");
  Serial.println("1 = 20%, 2 = 40%, 3 = 60%, 4 = 80%, 5 = 100%");
}

void loop() {
  if (Serial.available() > 0) {
    char caractere = Serial.read();  // Lécture du caractère reçu en entrée

    // Initialisation de la variable PWM
    int pwmValue = 0;

    // Les choix en fonction du caractère reçu
    if (caractere == '1') {
      pwmValue = 51;  // 20% de 255
      analogWrite(peltierPin, pwmValue);  // Application du signal PWM
    } else if (caractere == '2') {
      pwmValue = 102; // 40%
      analogWrite(peltierPin, pwmValue);

    } else if (caractere == '3') {
      pwmValue = 153; // 60%
      analogWrite(peltierPin, pwmValue);
    } else if (caractere == '4') {
      pwmValue = 204; // 80%
      analogWrite(peltierPin, pwmValue);
    } else if (caractere == '5') {
      pwmValue = 255; // 100%
      analogWrite(peltierPin, pwmValue);
    } else {
      Serial.println("Commande invalide, envoie 1 à 5.");
      return;
    }

    Serial.print("PWM réglé à : ");
    Serial.println(pwmValue);
  }
}

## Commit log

2026-10-07 changement de structure , ajout des fichiers , readme a mettre a jour aussi
    [Enrouleur_MPAP v2.stl, Test_Coffret_Conception Maison Energetique_1 v6(2).f3d, Test_Coffret_Conception Maison Energetique_1 v6.f3d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]
2026-10-09 Fix TCN75A reads, PWM dispatch and shutter trigger with host integration tests
    [Projet_Maison_Energetique.ino, test_sensor.cpp]
